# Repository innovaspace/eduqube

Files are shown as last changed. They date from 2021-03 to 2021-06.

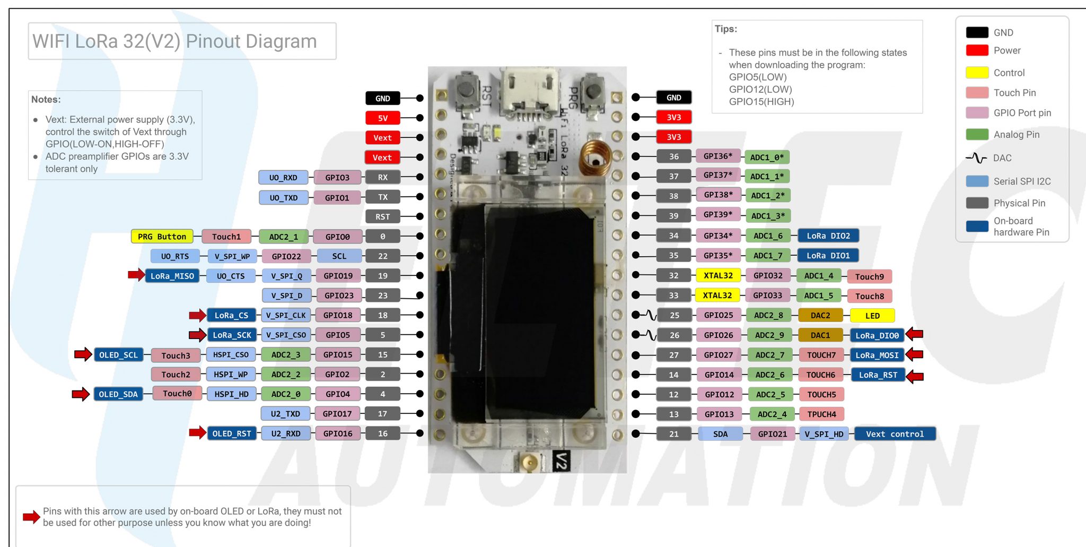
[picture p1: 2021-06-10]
manuals/WIFI_LoRa_32_V2-Heltec-pinout-diagram.jpg

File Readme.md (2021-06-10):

# EDUQUBE
PocketQube educative kit <br>

##### More info at
-  [Our website](https://www.innova-space.com/)
-  Follow us on [Twitter](https://twitter.com/innova_space)
-  And like us at [Facebook](https://www.facebook.com/innovaspace)

## Contents of this repository
Section TBD

## Installing

### OBC
#### Arduino IDE
Detailed instructions for installation in popular operating systems can be found at:
-  [Linux](https://www.arduino.cc/en/Guide/Linux) (see also the [Arduino playground](https://playground.arduino.cc/Learning/Linux))
-  [macOS](https://www.arduino.cc/en/Guide/MacOSX)
-  [Windows](https://www.arduino.cc/en/Guide/Windows)

#### Board Manager
 1. [Download and install the Arduino IDE](https://www.arduino.cc/en/Main/Software) (at least version v1.6.8)
 2. Start the Arduino IDE
 3. Go into Preferences
 4. Add ``` https://raw.githubusercontent.com/innovaspace/eduqube/main/boards/package_innovaspace_index.json ``` as an "Additional Board Manager URL"
 5. Open the Boards Manager from the Tools -> Board menu
 6. Search "Innova Space" and install the boards
 7. Select "Eduqube" from the Tools -> Board menu

### Ground Station (Heltec LoRa 32 v2)
[Heltec Installation tutorial](https://heltec-automation-docs.readthedocs.io/en/latest/esp32/quick_start.html)

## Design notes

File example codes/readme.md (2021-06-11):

# EDUQUBE EXAMPLE CODES

#### Mainboard 
Main OBC code, reads all the sensors data and sends it to the Ground Station via LoRa.

#### Ground Station
Recieves all the payload data, shows it in Serial Monitor and uploads it to an MQTT server. <br>
<br>
To upload the data to the MQTT server: 
- Uncomment the commented lines in main.ino
- Set WiFi SSID and password in config.h
- Set MQTT server IP in config.h

## Library Dependencies
To run each code, you need to have the following libraries installed:

#### Mainboard
- [RadioHead (RH_RF95)](http://www.airspayce.com/mikem/arduino/RadioHead/RadioHead-1.117.zip)
- TinyGPS++
- Adafruit Sensor
- Adafruit BME280 (or Adafruit BME680)
- MPU9250
- INA226

#### Ground Station
- RadioHead (RH_RF95)
- [OLED_I2C](http://www.rinkydinkelectronics.com/library.php?id=79)
- PubSubClient
- WiFi

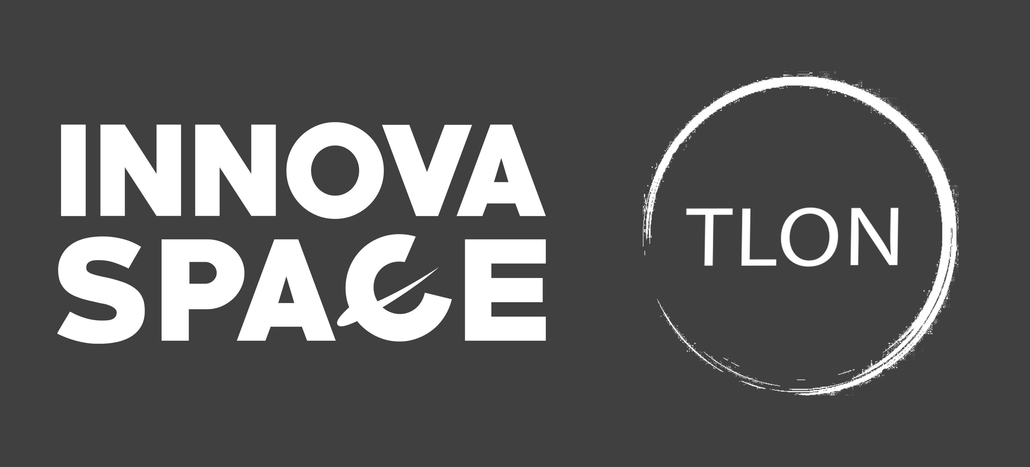
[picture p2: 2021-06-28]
Cloud/Dashboard/img/innova space 2-blanco.png

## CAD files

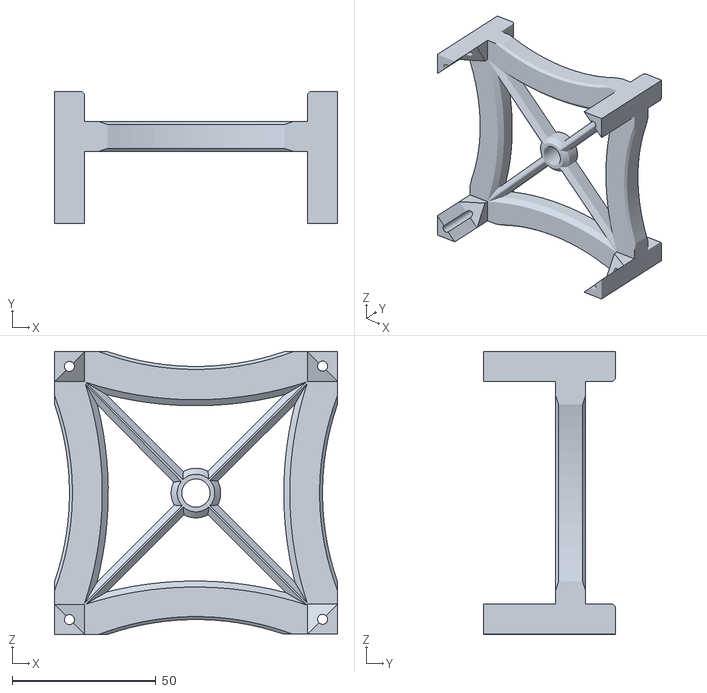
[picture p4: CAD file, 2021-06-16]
3d models/nanosat/CUBESAT_TOP.stl
98.4 x 46.1 x 98.4

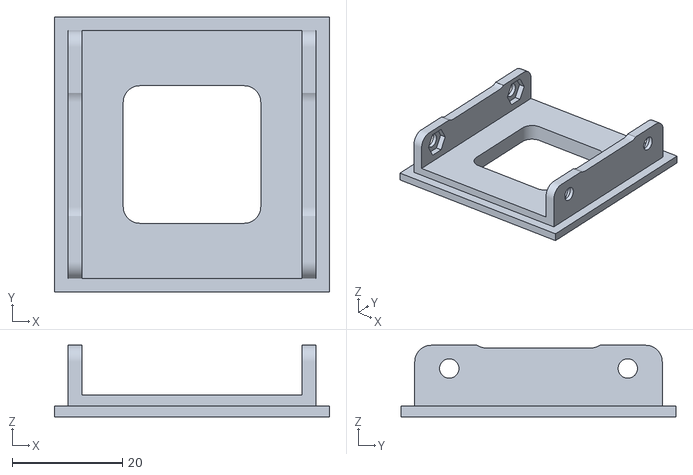
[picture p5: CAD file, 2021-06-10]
3d models/PQ Structure 1/pocketTop.stl
50.0 x 50.0 x 13.0

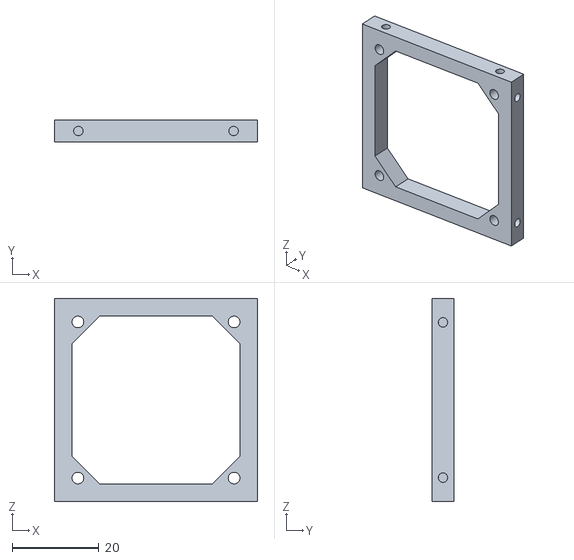
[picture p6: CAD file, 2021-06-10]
3d models/PQ Structure 2/frame_v3.stl
46.8 x 5.00 x 46.8

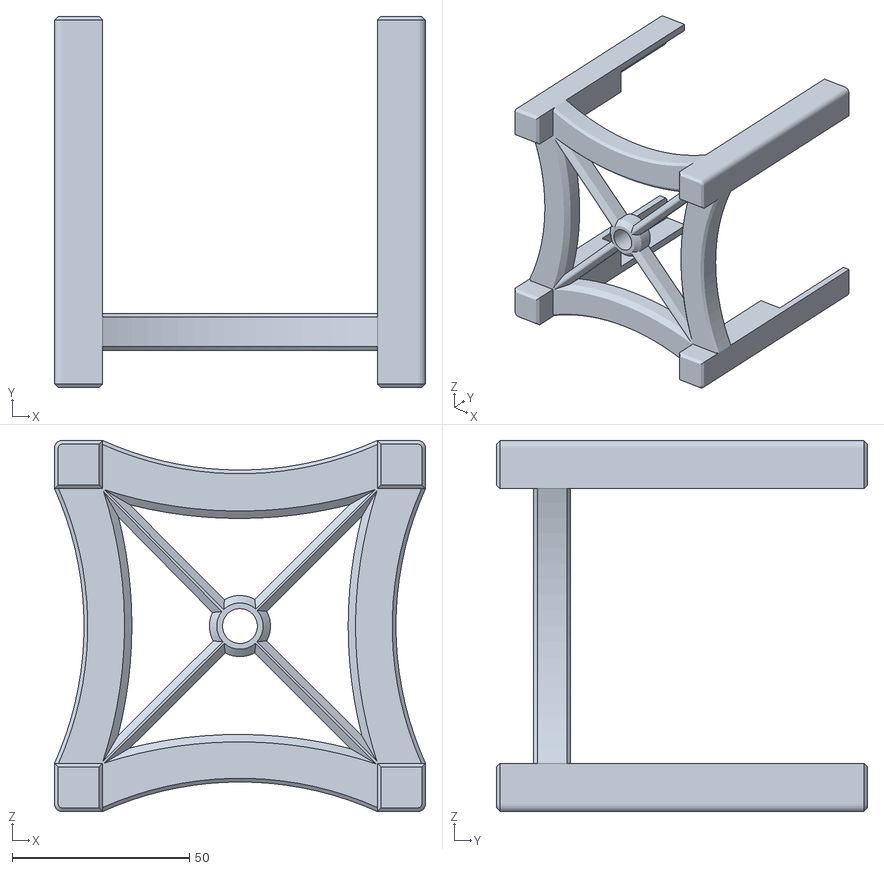
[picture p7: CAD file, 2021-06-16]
3d models/nanosat/CUBESAT CHASSIS_V1.0.stl
104.7 x 104.7 x 104.7

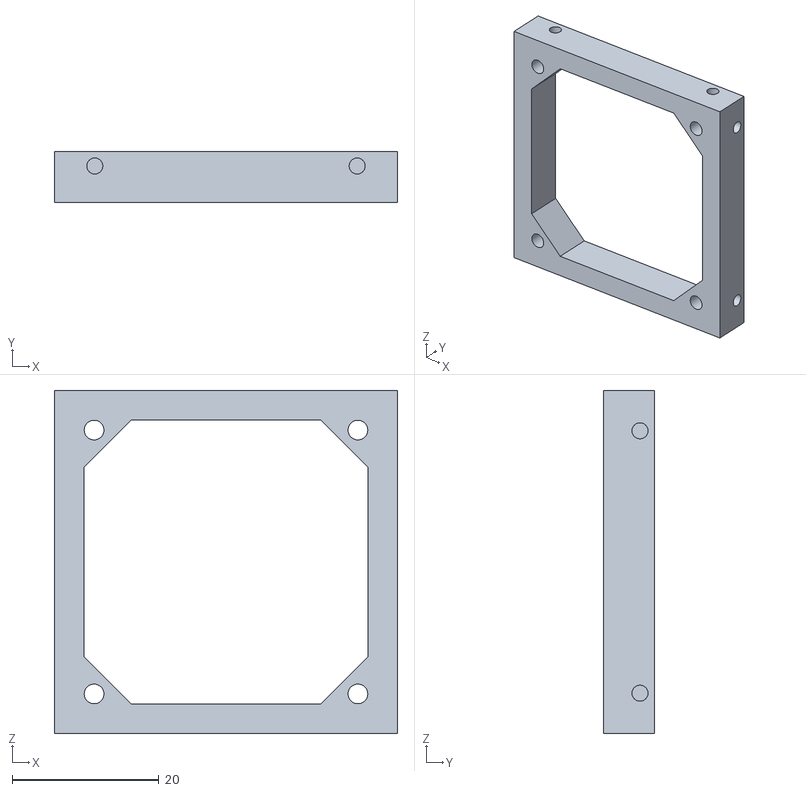
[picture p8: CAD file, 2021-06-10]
3d models/PQ Structure 2/base_v3.stl
46.8 x 7.00 x 46.8

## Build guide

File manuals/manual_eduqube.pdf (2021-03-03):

## Introduction to EduQube kit

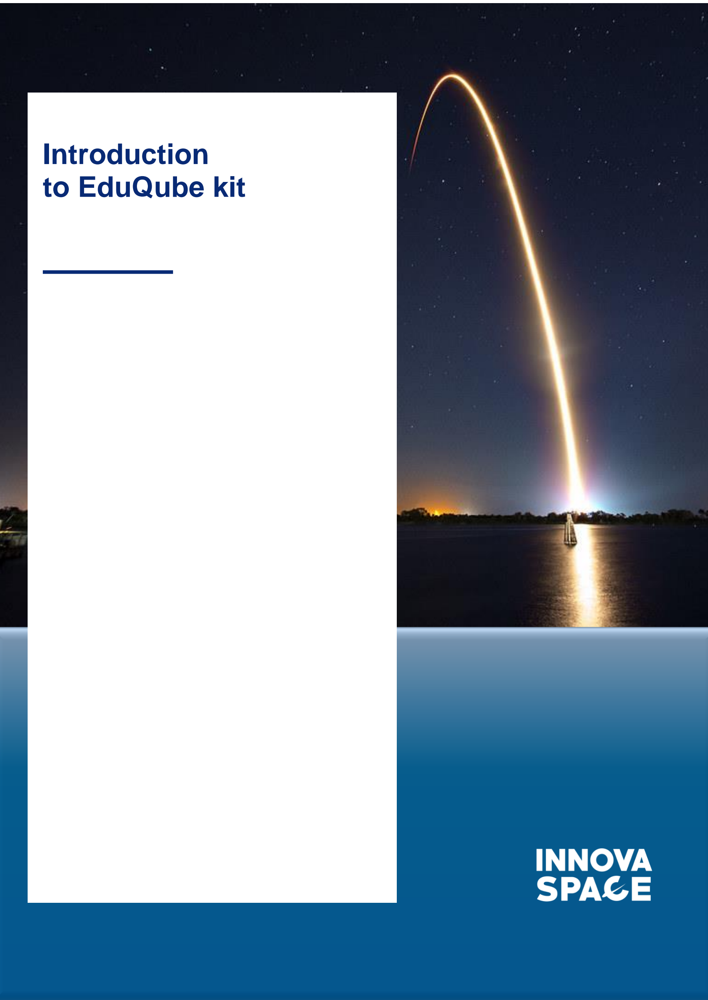
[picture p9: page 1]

2

# Index

## 1 | Overview

## 2 | OBC/COMMS

## 3 | EPS

## 4 | Payload

## 5 | Motherboard

## 6 | PCBs dimensions

## 7 | Structures

## 8 | The kit

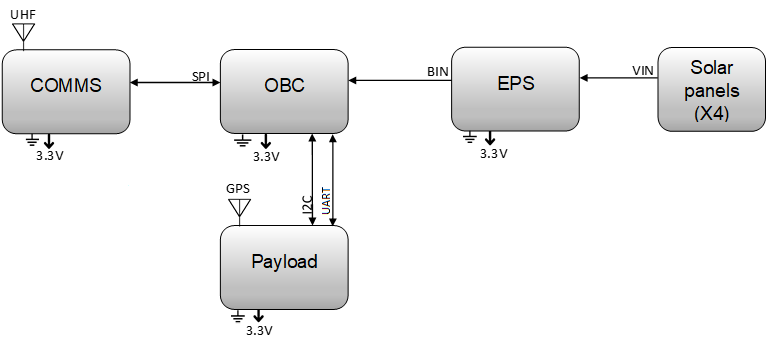
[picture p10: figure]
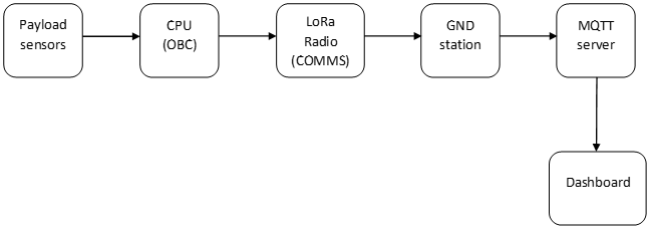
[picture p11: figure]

3

## 1.0 – Overview

Hardware

EduQube includes three separated modules containing the OBC/COMMS, EPS and Payload subsystems. All units feature PQ-10-standared connections.

Software and data visualization

The kit features a modular code for both satellite and GND station and a dashboard for data visualization.

Optional features

A 1P pocketqube structure and a CubeSat standard-sized motherboard (flatsat) are available as optional features. The motherboard brings the possibility to include an additional payload and to perform specific tests.

## 1.1 – EduQube block diagram

## 1.2 – EduQube data processing diagram

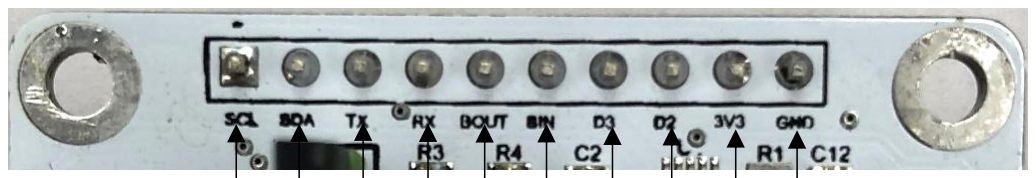
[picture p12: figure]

4

## 2.0 – OBC/COMMS

The OBC-v0X is an on-board computer and communications unit designed for EduQube educational kit. The board has been developed for data processing, telemetry functions and RF communication, hosting these subsystems in a unique board. Its architecture includes a 32-bit SAMD21 G microcontroller and a RFM95W 915MHz LoRa radio module (OBC-v01). The OBC-v02 features a SX1262 1GHz LoRa radio module.

Main features:

- Microchip SAMD21-G 32-bit, 48MHz microcontroller.
- PQ-10 Standard header.
- 4Mb flash memory.
- Texas Instruments current monitor.
- USB-C 2.0 receptacle.
- SMA and UFL connectors.
- Supports Arduino and Python programming.

## 2.1 – OBC/COMMS Pinout (OBC_v01 and OBC_v02)

1 2 3 4 5 6 7 8 9 10

Pin number | Name | Pin functions
1 | SCL | I2C communication SCL pin.
2 | SDA | I2C communication SDA pin.
3 | TX | UART communication TX pin.
4 | RX | UART communication RX pin.
5 | BOUT | Current control output.
6 | BIN | Current control input.
7 | D3 | Digital I/O pin.
8 | D2 | Digital I/O pin.
9 | 3V3 | +3.3v VDD
10 | GND | VSS

## 2.1.1 – OBC/COMMS USB power source

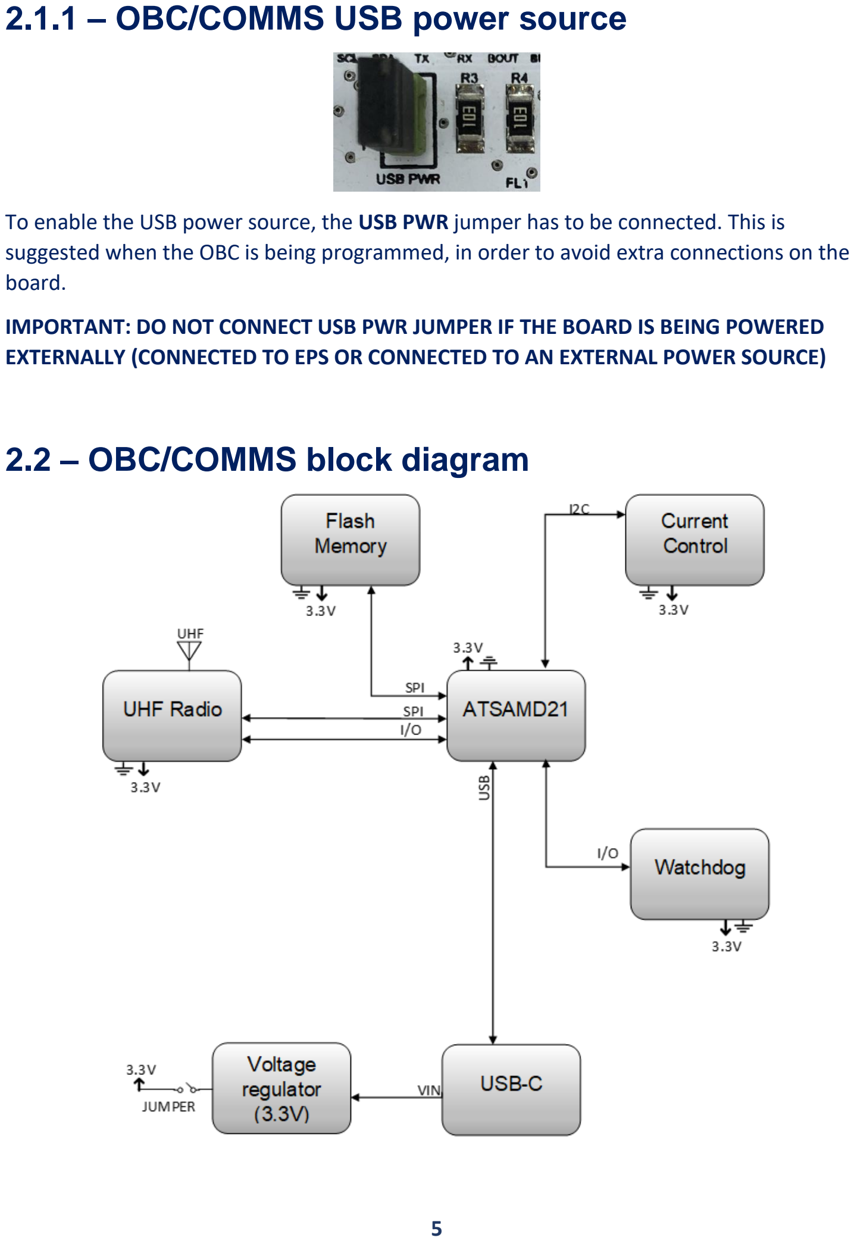
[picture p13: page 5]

5

To enable the USB power source, the USB PWR jumper has to be connected. This is suggested when the OBC is being programmed, in order to avoid extra connections on the board.

IMPORTANT: DO NOT CONNECT USB PWR JUMPER IF THE BOARD IS BEING POWERED EXTERNALLY (CONNECTED TO EPS OR CONNECTED TO AN EXTERNAL POWER SOURCE)

## 2.2 – OBC/COMMS block diagram

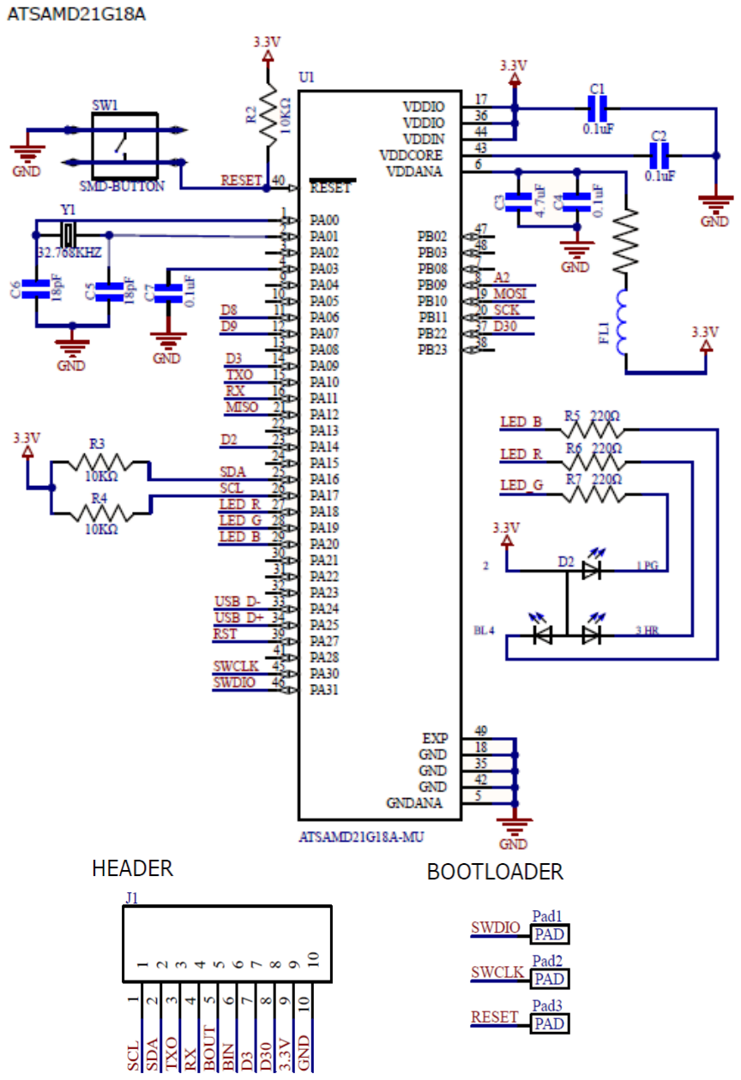
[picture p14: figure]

6

## 2.3 – OBC/COMMS schematic design

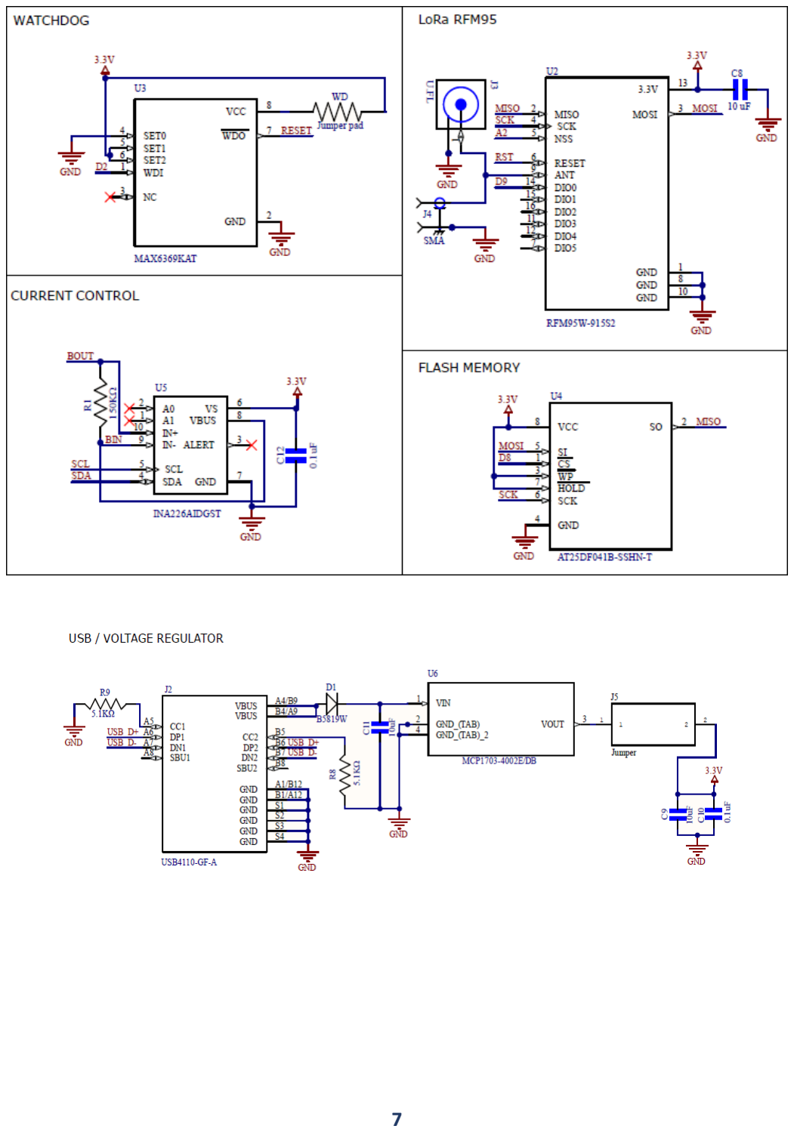
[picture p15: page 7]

7

8

## 3.0 – EPS

The EPS-v01 unit provides the EduQube kit an efficient power management. This module features two ST SPV1040, which includes an embedded MPPT, a high-efficiency solar battery charger and a built-in current control. The EPS-v01 supports up to four solar panels, reaching a maximum output power of 3.3W.

Main features:

- Two ST SPV1040 high-efficiency solar battery chargers and MPPTs.
- PQ-10 Standard header.
- 1A voltage regulator.
- Current control.
- 3.3W max. Output power.

## 3.1 – EPS Pinout

1 2 3 4 5 6 7 8 9 10

Pin number | Name | Pin functions
1 NC
2 NC
3 NC
4 NC
5 | BOUT | Current control output.
6 | BIN | Current control input.
7 | D3 | Digital I/O pin.
8 | D2 | Digital I/O pin.
9 | 3V3 | +3.3v VDD
10 | GND | VSS

## 3.2 – EPS block diagram

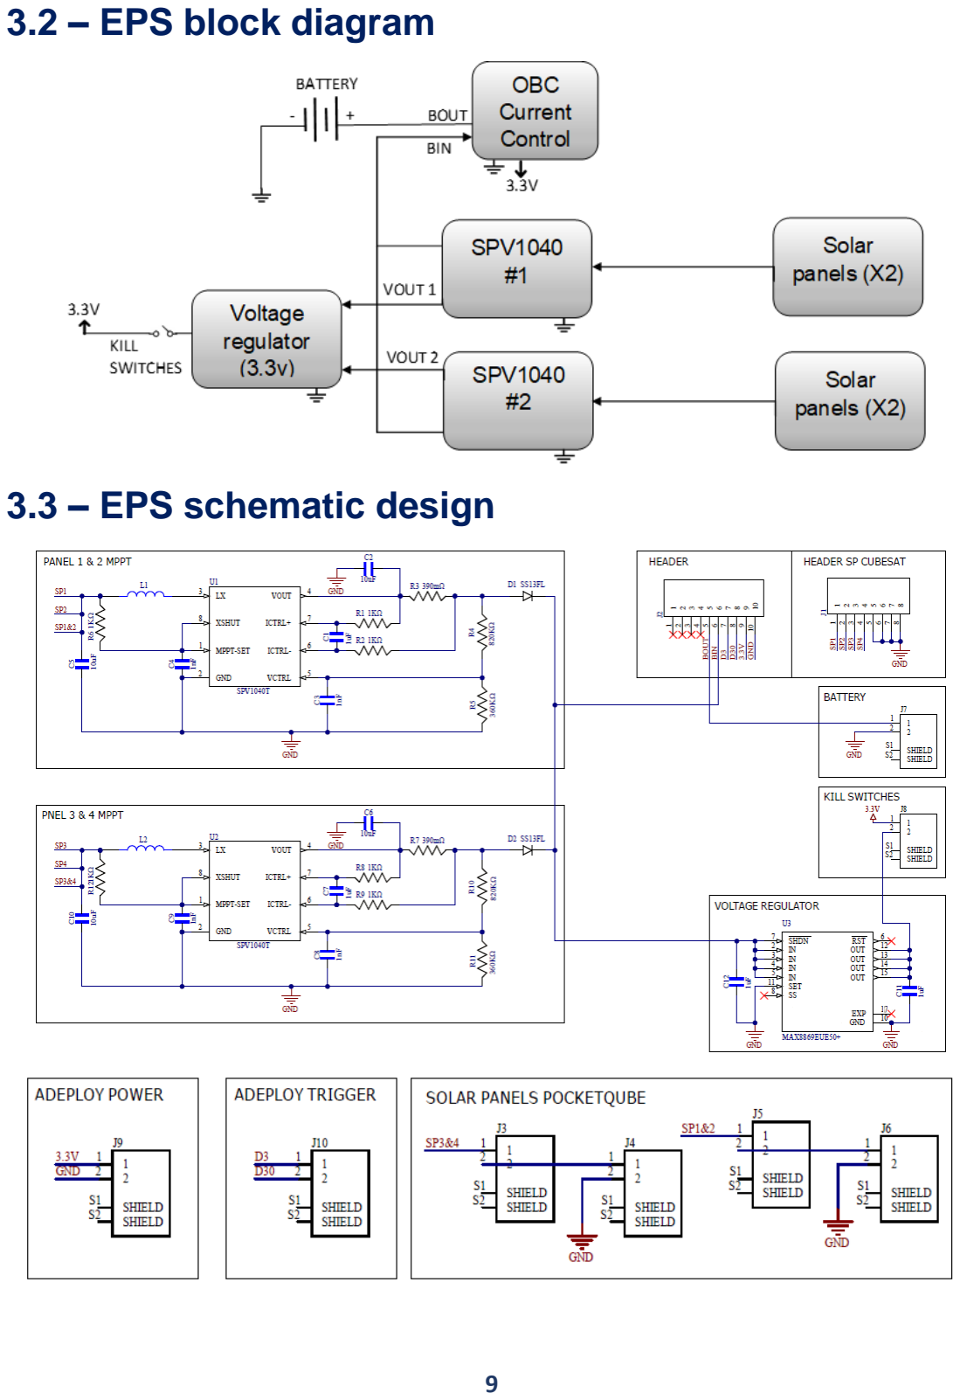
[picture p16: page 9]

9

## 3.3 – EPS schematic design

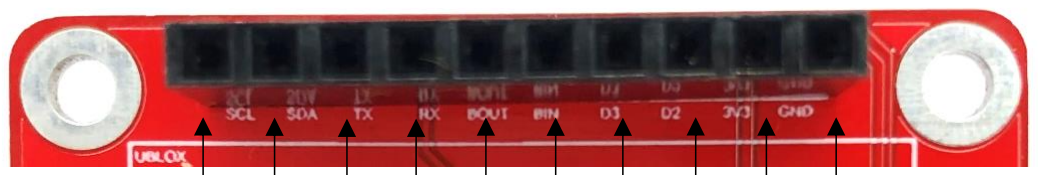
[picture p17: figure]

10

## 4.0 – Payload

This unit includes a gyroscope, magnetometer and accelerometer and a weather sensor (temperature, humidity, pollution and altitude), as well as an Ublox GPS module. The board is connected to the OBC unit by a PQ-10 standard header, featuring I2C and UART communication, and two I/O digital pins.

Main features:

- Bosch BME680 temperature, humidity, altitude and pollution sensor.
- PQ-10 Standard header.
- TDK MPU9250 9-axis accelerometer, gyroscope, magnetometer.
- GPS

## 4.1 – Payload Pinout

1 2 3 4 5 6 7 8 9 10

Pin number | Name | Pin functions
1 | SCL | I2C communication SCL pin.
2 | SDA | I2C communication SDA pin.
3 | TX | UART communication TX pin.
4 | RX | UART communication RX pin.
5 NC
6 NC
7 NC
8 NC
9 | 3V3 | +3.3v VDD
10 | GND | VSS

## 4.2 – Payload block diagram

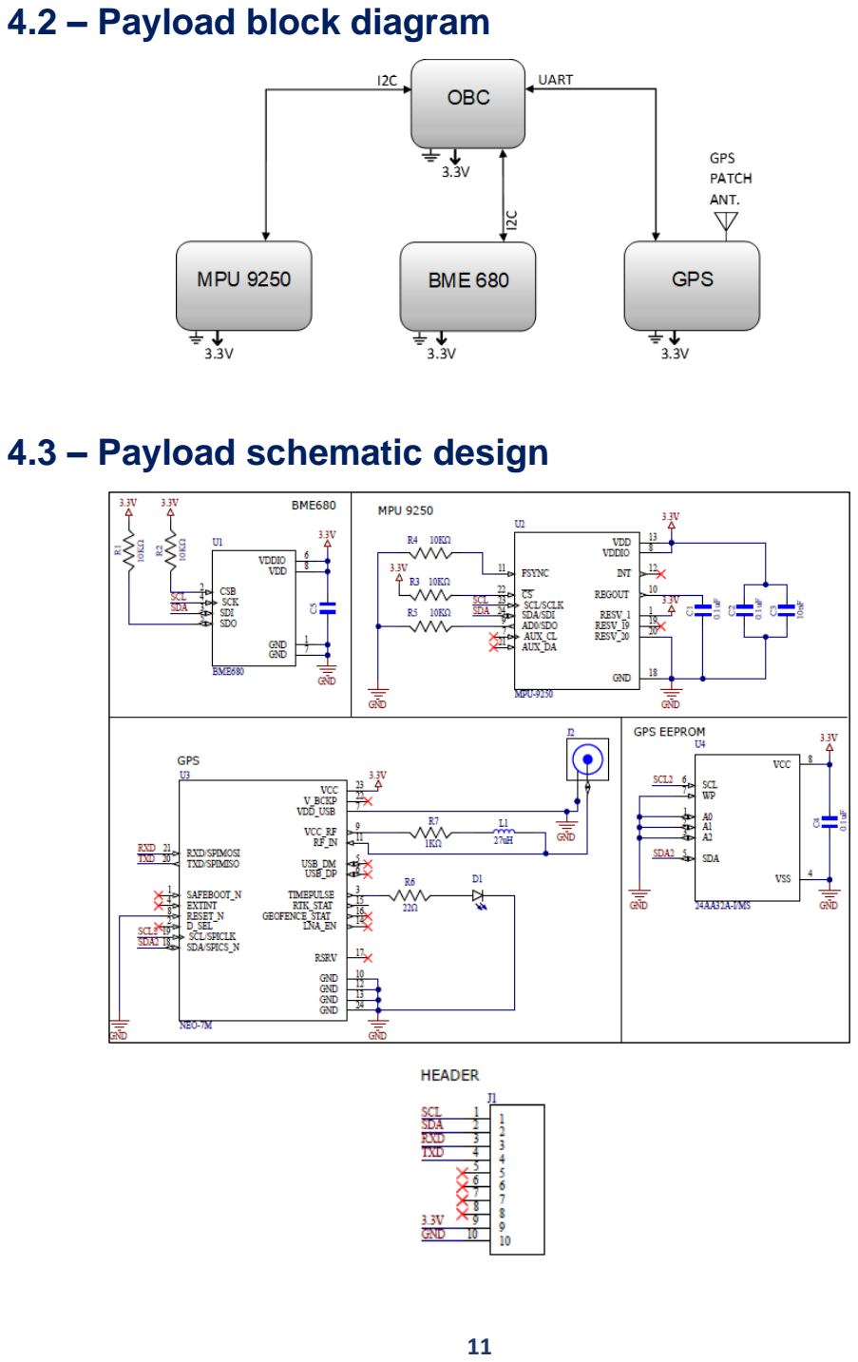
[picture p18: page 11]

11

## 4.3 – Payload schematic design

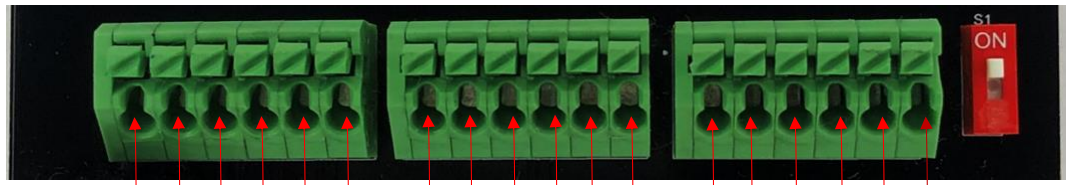
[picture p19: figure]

12

## 5.0 – Motherboard

As an optional feature for EduQube, the motherboard (flatsat) brings the possibility to perform specific tests and to add a custom payload module. The board is CubeSat-standard-sized, and its purpose is to integrate all the EduQube modules.

Main features:
- 18650 battery holder (battery not included).
- 3.5mm stereo jack RBF switch housing (male not included).
- External power source input (with built-in 3.3V regulator).
- Solar panels inputs.
- Additional payload slot.

## 5.1 – Motherboard Pinout

1 2 3 4 5 6 | 7 8 9 10 11 12 | 13 14 15 16 17 18

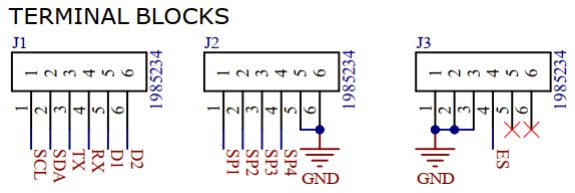
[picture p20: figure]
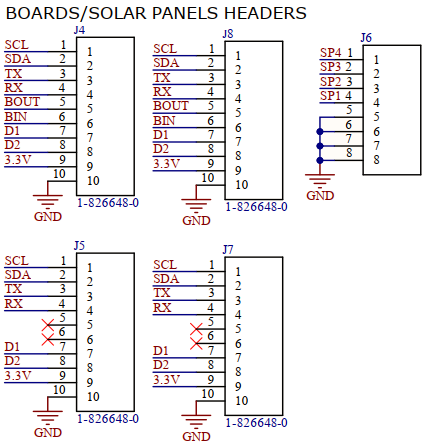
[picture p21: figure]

13

## 5.2 – Motherboard schematic design

Pin number | Name | Pin functions
1 | SCL | I2C communication SCL pin.
2 | SDA | I2C communication SDA pin.
3 | TX | UART communication TX pin.
4 | RX | UART communication RX pin.
5 | D1 | Digital I/O pin.
6 | D2 | Digital I/O pin.
7 | SP1 | Solar panel input.
8 | SP2 | Solar panel input.
9 | SP3 | Solar panel input.
10 | SP4 | Solar panel input.
11 | GND1 | VSS
12 | GND2 | VSS
13 | GND3 | VSS
14 | GND4 | VSS
15 | GND5 | VSS
16 | ES | External power source +VCC pin.
17 NC
18 NC

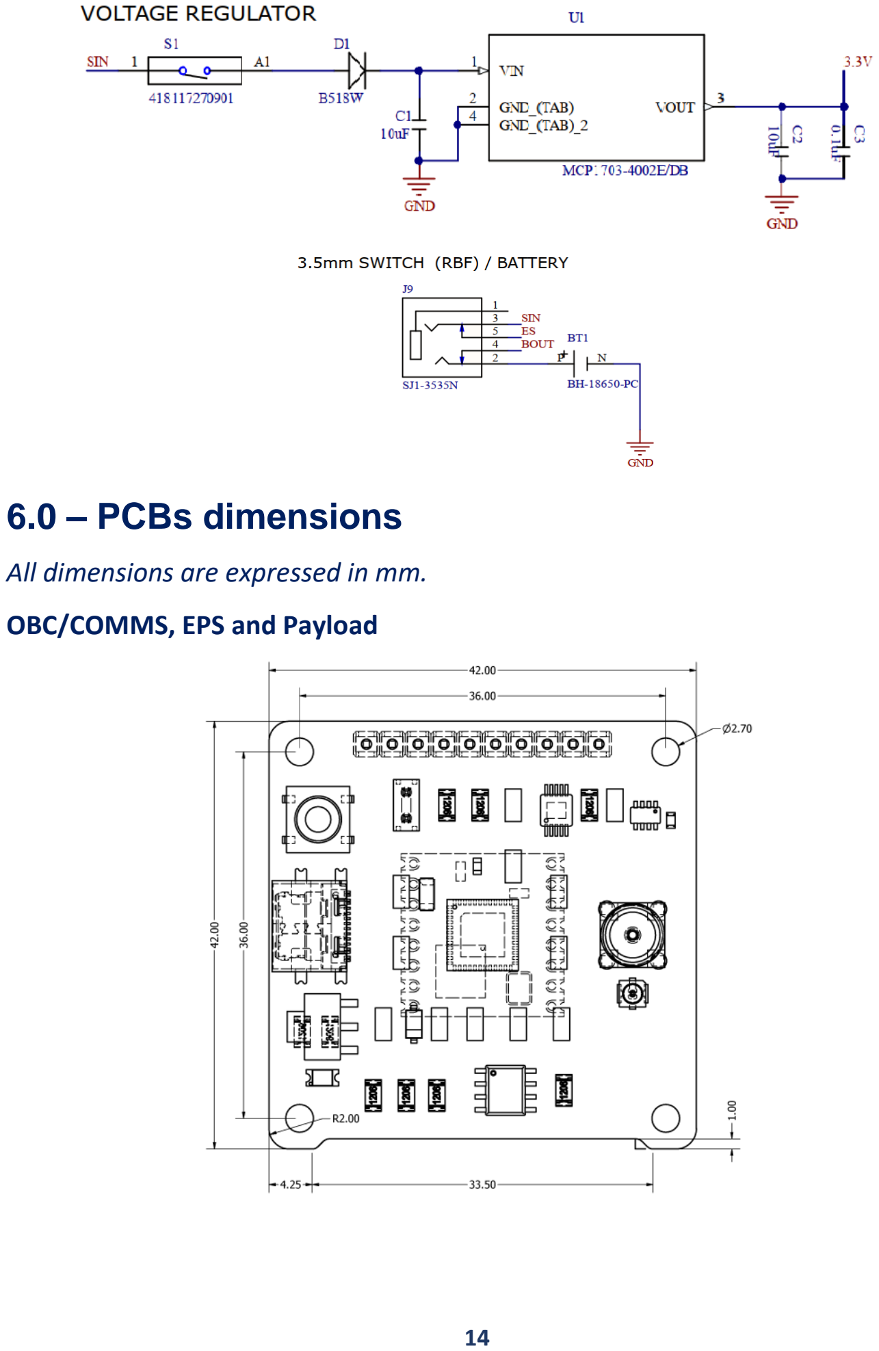
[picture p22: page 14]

14

## 6.0 – PCBs dimensions

All dimensions are expressed in mm.

OBC/COMMS, EPS and Payload

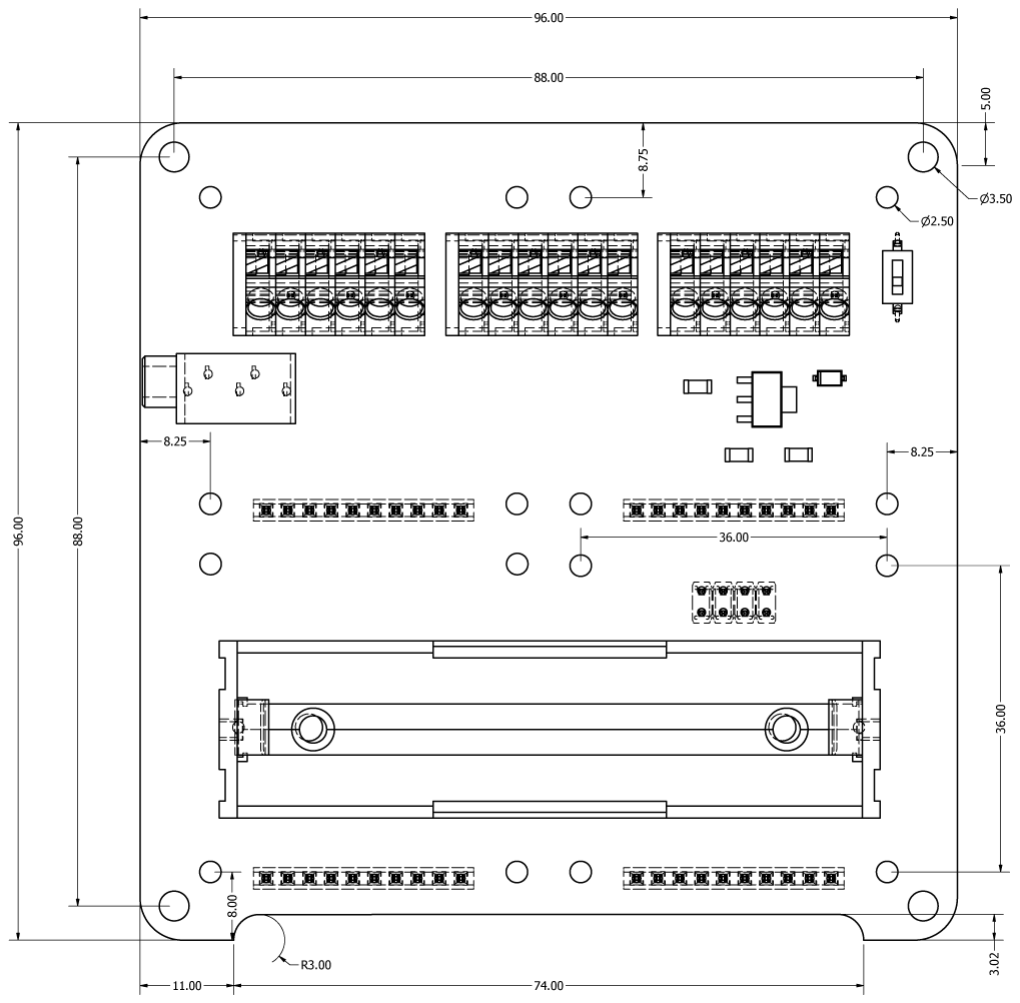
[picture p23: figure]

15

Motherboard

## 7.0 – Structures

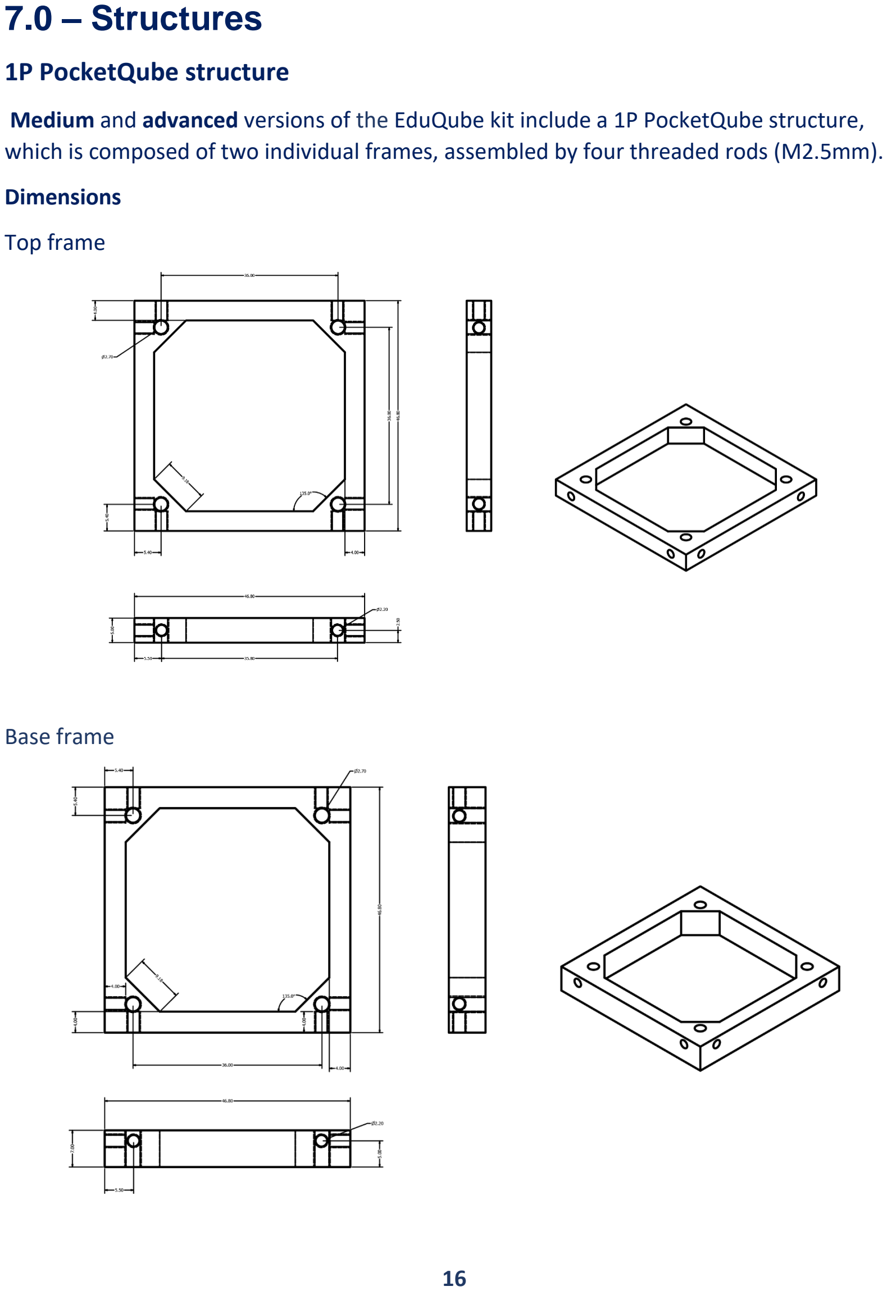
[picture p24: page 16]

16

1P PocketQube structure

Medium and advanced versions of the EduQube kit include a 1P PocketQube structure, which is composed of two individual frames, assembled by four threaded rods (M2.5mm).

Dimensions

Top frame

Base frame

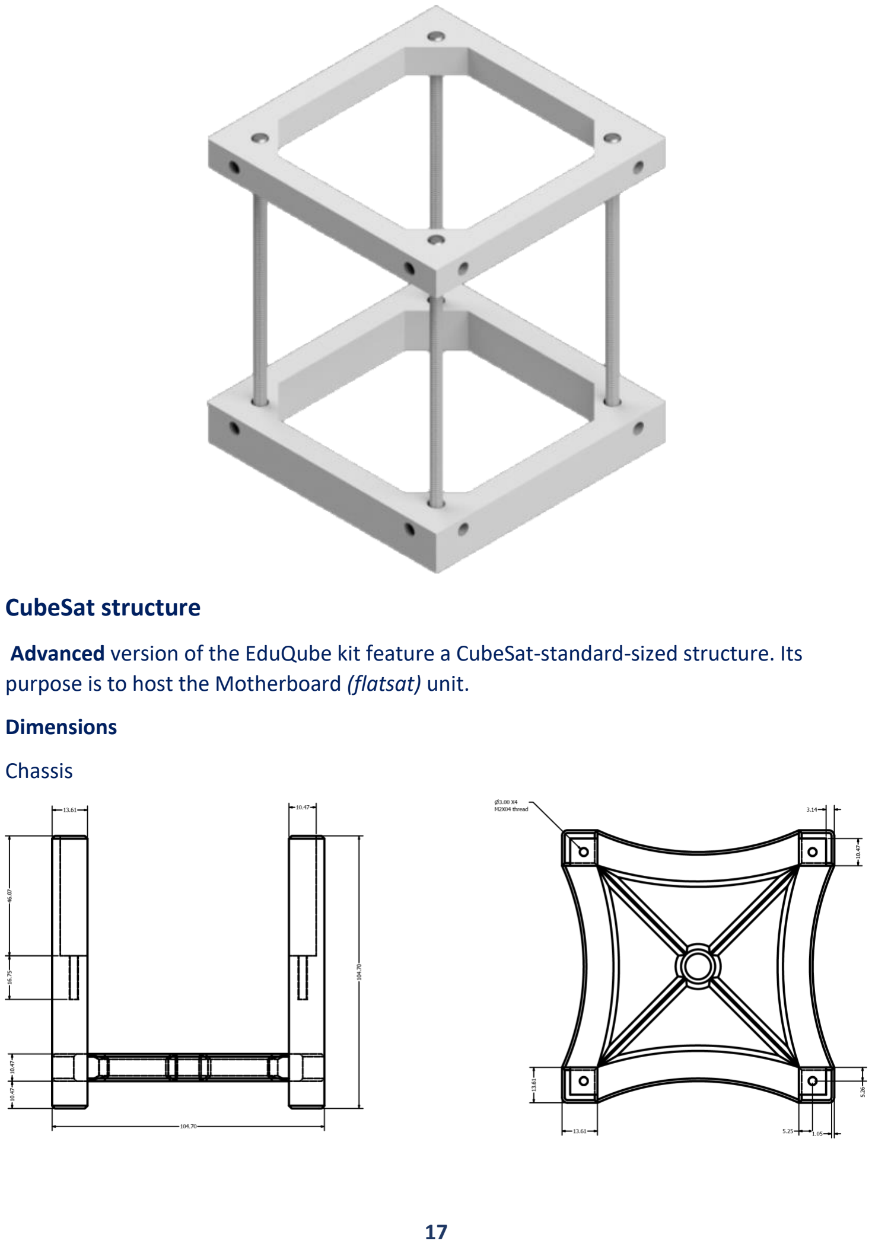
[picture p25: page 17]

17

CubeSat structure

Advanced version of the EduQube kit feature a CubeSat-standard-sized structure. Its purpose is to host the Motherboard (flatsat) unit.

Dimensions

Chassis

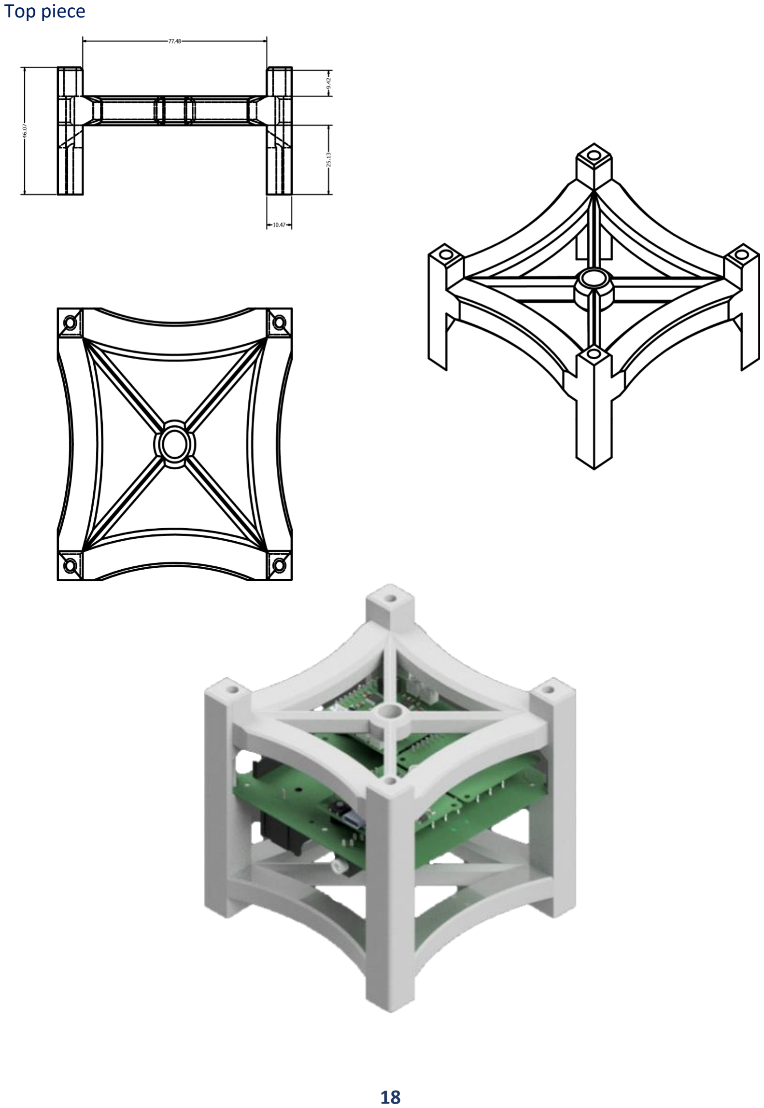
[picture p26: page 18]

18

Top piece

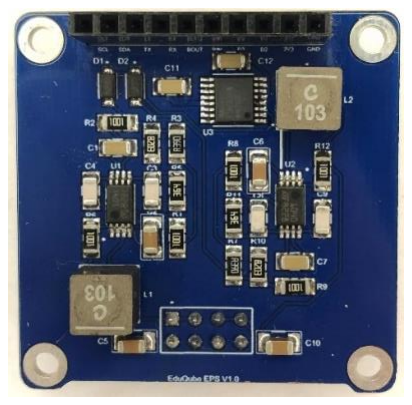
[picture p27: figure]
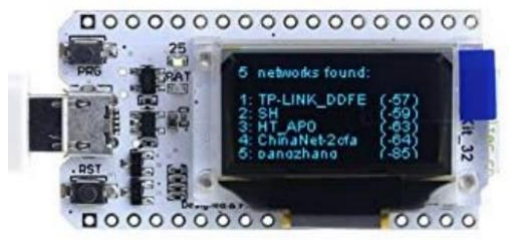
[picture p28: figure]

19

## 8.0 – Kit

Basic version includes:

OBC/COMMS board | EPS board | Payload board

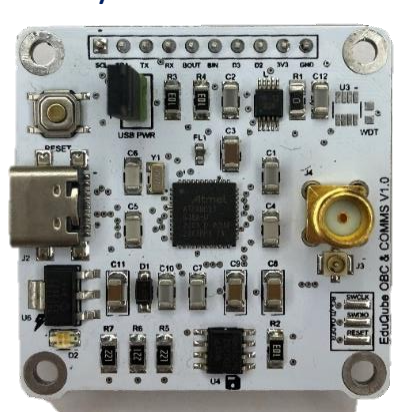
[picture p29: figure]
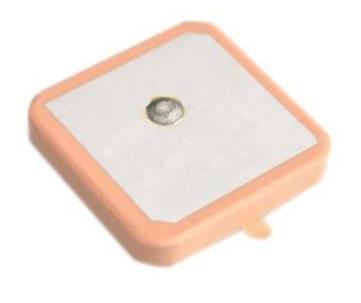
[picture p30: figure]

Solar panels 5x5 cm.(X4) | RF antenna (433 MHz) | GPS patch antenna

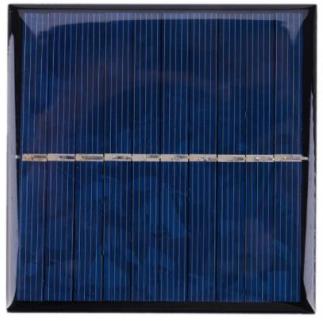
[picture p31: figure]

- Software
- Structures CAD files (3D-printable)

Medium version adds (over de Basic version):

Motherboard | Ground station (ESP32 OLED) | Solar panels 5x5 cm.(X5) Solar panels 10x10 cm.(X5)

Advanced version adds (over de Medium version):

- Structures (see section 7.0 – Structures).
- Exterior PCBs

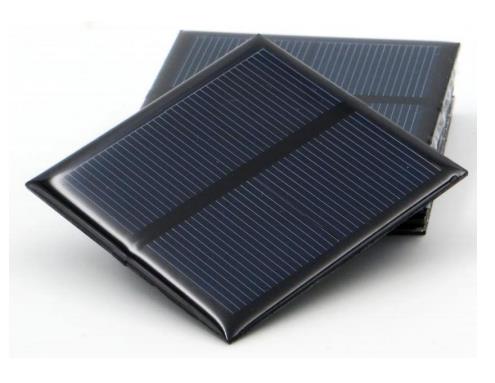
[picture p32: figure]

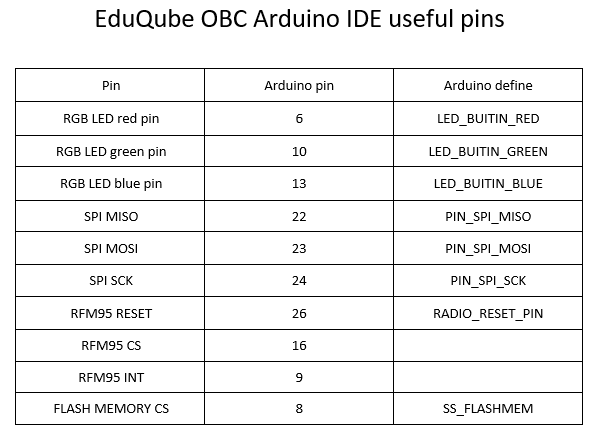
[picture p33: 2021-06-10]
manuals/EduQube OBC Arduino pins.png

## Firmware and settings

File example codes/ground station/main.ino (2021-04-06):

//-----------------------------------------------------------------------------
//  main.ino
//  Ground Station
//  
//  Main program
//  sequence of configuration functions is ordered in setup()
//  sequence of functions to be excecuted in loop in loop()
//-----------------------------------------------------------------------------

#include <Arduino.h>
#include "radio.h"
#include "config.h"
#include "mqtt.h"
#include "wifi_c.h"
#include "upload.h"
#include "display.h"

//-----------------------------------------------------------------------------
//  Setup
//-----------------------------------------------------------------------------
void setup()
{
    Serial.begin(9600);
    oled_setup();
    radio_setup();
    //wifi_setup();
    //mqttConnect();
    //upload_data();
    print_status();
}
//-----------------------------------------------------------------------------
//  Loop
//-----------------------------------------------------------------------------
void loop()
{
    radio_loop();
    //upload_data();
    //mqtt_loop();
}

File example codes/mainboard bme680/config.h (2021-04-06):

//-----------------------------------------------------------------------------
//  config.h
//  Mainboard BME680
//  General configuration file
//-----------------------------------------------------------------------------

#ifndef CONFIG_H
#define CONFIG_H

//-----------------------------------------------------------------------------
//  LoRa
//-----------------------------------------------------------------------------
#define TX_POWER 20         // Transmission power in dBm (range = 2-20)
#define SF 12               // Spreading Factor (range = 6-12)
#define RFM95_CS 16         // Pin connected to radio Chip Select
#define RFM95_INT 9         // Pin connected to radio interrupt pin
#define FREQ 915.0          // RFM95 transmission frequency

//-----------------------------------------------------------------------------
//  BME680 & MPU9250
//-----------------------------------------------------------------------------
#define SEALEVELPRESSURE_HPA (1026)     // BME680 Sea level pressure (calibration)
#define MPU_I2C 0x68                    // MPU9250 I2C address

//-----------------------------------------------------------------------------
//  Watchdog
//-----------------------------------------------------------------------------
#define wdi_reset 2                     // Watchdog reset pin

//-----------------------------------------------------------------------------
//  GPS
//-----------------------------------------------------------------------------
static const uint32_t GPSBaud = 9600;   // GPS module baudrate

//-----------------------------------------------------------------------------
//  FLASH Memory
//-----------------------------------------------------------------------------
#define AT25_CS 8                       // flash memory Chip Select

//-----------------------------------------------------------------------------
//  INA226 Current / Power Monitor
//-----------------------------------------------------------------------------
#define rshunt 0.06                     // INA226 Shunt resistor value
#define maxcurrent 1                    // Max expected current (in Amperes)

#endif
